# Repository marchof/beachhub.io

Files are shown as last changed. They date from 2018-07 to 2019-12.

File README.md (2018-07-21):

BeachHub.io
===========

Solar powered Git Repository and CI Server for beach usage built for the
[JCrete Unconference](http://www.jcrete.org).

* [Hardware](doc/hardware.md)
* [Energy Considerations](doc/energy.md)
* [Router Setup](doc/router.md)
* [System Setup](doc/setup.md)

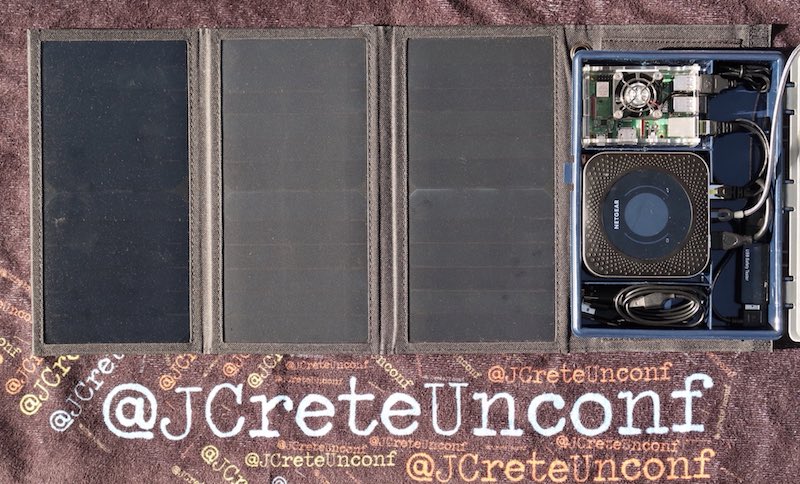
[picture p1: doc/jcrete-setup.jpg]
JCrete Setup


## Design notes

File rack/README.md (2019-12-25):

# 3D Models for Raspberry Pi Racks

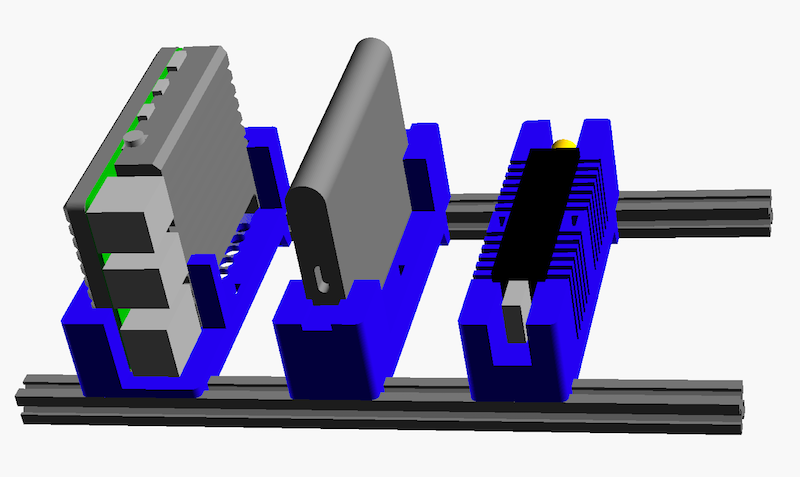
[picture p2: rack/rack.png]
Pi Rack


The rack is build from two supporting maker beams (10mm x 10mm).
There are holders for different modules I use for Raspberry Pi setups:

* Raspberry Pi with passive cooling Armor case
* External Samsung SSD
* Nooelec NESDR SMArt

These components are placed into the holders and fixed with a cable strap.

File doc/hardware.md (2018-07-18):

# Hardware

The following requirements were to consider when building the beachhub.io data center:

* **Power Supply:** The entire system should only be operated on solar power. Therefore total power consumption must be
  handled by a portable solar panel. To guarantee continuous operations a re-chargeable battery should buffer
  temporary drops in the solar power supply. For ease of integration I only considered distributing power with USB
  connections.
* **WiFi Access:** To make the hub accessible on the beach a WiFi network should be provided which lasts for at least a
  handful of devices.
* **Internet Connectivity:** The hub itself should have internet access and should also be accessible from the internet
  when active. Also it would be nice if the WiFi network could serve as a hotspot.

Considering these requirements I came up with the following setup:

## Solar Panels

I'm a big fan of Anker hardware for cables and power supplies. So my natural
choice was their *PowerPort Solar Charger 21W*. It has two USB ports with up to
2.4A each (but only 3A in total). You may easily figure out that this makes 15W
and not 21W as the name suggests -- but hey, this is how product marketing
works. Fortunately this is still enough for our setup. The panel is somehow
flexible and can be folded to a flat, portable package. The solar cells are
covered in a robust canvas which has four loops (each in every corner) so the
panel can be easily installed in different environments.

## Server

As a widely adopted low energy computing platform I picked a *Raspberry Pi 3 B+*
board. It has all the connectivity we need and is powerful enough to host Git
repos and maybe provide some simple means of continuous integration. I added
two persistent volumes to it:

1. A 32GB micro SD card for the operating system and all software
2. A small 64GB USB stick for all data (Git repos)

Separating the data from the system volumes allows me to update or re-stage the
system on the latter without worrying about the data.

To help with cooling under beach conditions I attached the heat sinks delivered
with the case and installed a small USB powered fan. It looks like the this
combination significantly reduces CPU temperature.

## 4G WIFI Router

While quite expensive though the best option currently on the market seems to be the Netgear Nighthawk M1. While it has
a quite compact form factor it encapsulates a gigabit 4G an WIFI router. A comparison with a stationary Huawai B593s-22
under identical, poor signal conditions showed that the signal received by the M1 is significant lower and so is the
bandwidth (Huawai 20 MBit/s down, 6 MBit/s up / Netgear 5 MBit/s down, 4MBit/s up). Maybe the signal strength can be
improved with external antennas. For this the M1 has two TS-9 connectors.

The router can be flexible configured and especially allows to map ports from the public IP to our Raspberry Pi for
access to BeachHub from the public internet (i.e. people not spending a nice day at the same beach). The WiFi provides a
2.4 GHz and a 5 GHz band and allows up to 20 concurrent user. Few even stationary routers come with such a feature set.

On top of this the hardware and its connectivity is ideal for our setup: There is one ethernet port which can be used for a
direct, reliable connection to the Raspberry Ri. It also comes with two different USB port: A USB-C port can be used for
charging from the solar panel. An additional USB 2.0 port provides power from its internal battery. We connect the raspberry
to this port for power supply. The nice side effect is that the internal router battery now serves as a kind of UPS for the
Raspberry Pi in case we have temporary drops in the solar power. What is also nice is that the power supply of the USB 2.0
port is switched with the router. So we can power up and down our whole data center with a single button.

## Mini USB Fan

As small small enough to directly fit in the Raspberry Pi case should help to
control the CPU temperature. It has an USB cable and its power consumption is
so small that it can be directly plugged in one of the Pi's USB ports.

## Wiring

For a minimal setup the wiring is quite simple:

- Long UBS 2.0/USB-C cable to connect the solar panel with the router (power supply)
- Short USB 2.0 cable to connect the router with the Raspberry Pi (power supply)
- The mini fan is plugged directly to a Raspberry Pi's USB port (power supply)
- Short ethernet cable to connect the router with the Raspberry Pi (network)

## Additional Hardware

- **Eithernet Hub** A small USB powered hub to connect additional devices if required.
- **Power Monitor** This small device can be plugged into a USB connection and shows voltage, current
  power and accumulated energy consumption. This device helped me to figure out what the solar panel
  actually can handle.

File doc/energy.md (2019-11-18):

# Power Management

With the USB tester plug I measured the following currents for the different BeachHub
devices. As all devices are powered with USB connectors the voltage is 5V in all cases.

Device                  | Min    | Max   
----------------------- | ------ | ------
Router (not charging)   | 0.25 A | 0.45 A     
Raspberry Pi 3 B+       | 0.38 A | 0.75 A
Mini Fan                | 0.12 A | 0.16 A

--> You can quantify power requirements of any specific device you have with lsusb -v and the MaxPower property.

## Bad Cables

It turned out that some of the USB cables I tested cause such a significant voltage
drop that the Raspberry Pi goes off. To avoid such surprises I checked all cables
used in BeachHub with the USB tester:

1. Find a constant and strong power source (charger or large power bank)
2. Connect a heavy load (empty smart phone oder battery back) with a the USB tester
   to the power source. Write down the voltage shown by the tester.
3. Now insert the cable in question between the power source and the USB tester.
   Note the voltage shown now.
 
If the voltage is decreased by more that 0.2V or the voltage measured in step 3
is less than 4.8V you can't run a Raspberry Pi reliable on this cable.

## Under Voltage

If the supplied voltage is too low the CPU gets throttled. With the following command you can check whether this or was the case:

    vcgencmd get_throttled
    
The bits in the returned integer have the following meanings:

| Bit | Meaning |
|:---:|---|
| 0 | Under-voltage detected |
| 1 | Arm frequency capped |
| 2 | Currently throttled |
| 3 | Soft temperature limit active |
| 16  | Under-voltage has occurred |
| 17  | Arm frequency capped has occurred |
| 18  | Throttling has occurred |
| 19  | Soft temperature limit has occurred |

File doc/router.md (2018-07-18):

# Router Setup

I performed the following steps with the Netgear Nighthawk M1 router using its web
interface on `http://192.168.1.1`.

1. **Router Password**
   On first login the router password must be set
2. **Mobile Internet**
   For most mobile operators the SIM card should be detected without further APN
   configuration. Make sure the SIM security is deactivated or you need to enter
   PIN on every startup. You may also enable the roaming option if you want to
   run the device on foreign beaches. In this case the SIM should have an
   international data plan of course.
3. **Firmware Update**
   For the latest bug fixes perform an update under *Administration / Firmware Update*.
4. **WiFi**
   Under *Setup / Wifi Profiles* select *2.5 GHz Only* to save energy.
   Under *Setup / Wireless* set a SSID and password for the 2.4 GHz network.
   For best wireless experience set the WiFi standby to *60 Minutes* and the
   range to *Long*.
5. **USB Port**
   As we use the USB port for charging only under *Setup / Mobile Router Setup*
   set *Tethering* to *Charge only*.
6. **Ethernet**
   To avoid disconnecting the Raspberry Pi from under *Setup / Mobile Router Setup*
   select *Disabled* for *Ethernet Standby*.

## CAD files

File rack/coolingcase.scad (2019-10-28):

// Beachhub Pi Rack Geometries

// Global resolution
$fs = 0.1;  // Don't generate smaller facets than 0.1 mm
$fa = 5;    // Don't generate larger angles than 5 degrees

use <raspberrypi.scad>;

module _cone() {
  translate([0.0, 0.0, -5.0]) cylinder(h=18.0, r=2.0);
  translate([0.0, 0.0, 13.0]) cylinder(h=2.0, r1=2.0, r2=0.0);
  translate([0.0, 0.0, -7.0]) cylinder(h=2.0, r1=0.0, r2=2.0);
}

module _block() {
  hull() {
    translate([40.5, 26.0, 0.0]) _cone();
    translate([40.5, -26.0, 0.0]) _cone();
    translate([-40.5, 26.0, 0.0]) _cone();
    translate([-40.5, -26.0, 0.0]) _cone();
  }
}

module coolingcase() {
  color("gray")
  difference() {
    _block();
    // cooling top
    for (y = [-22.0 : 4.7 : 17.0])
      translate([-45.0, y, 13.0]) cube([90.0, 2.3, 4.0]);
    // cooling bottom
    for (y = [-22.0 : 4.2 : 22.0])
      translate([-45.0, y, -9.0]) cube([90.0, 2.0, 4.0]);
    // board
    translate([-45.0, -30.0, 0.0]) cube([90.0, 60.0, 2.0]);
    // USB/network ports
    translate([23.0, -30.0, 0.0]) cube([23.0, 60.0, 20.0]);
    // GPIO pins
    hull() {
      translate([14.5, 22.0, 0.0]) cylinder(h=18.0, r=2.0);
      translate([-35.5, 22.0, 0.0]) cylinder(h=18.0, r=2.0);
      translate([14.5, 30.0, 0.0]) cylinder(h=18.0, r=2.0);
      translate([-35.5, 30.0, 0.0]) cylinder(h=18.0, r=2.0);
    }
  }
}



//pi4();
coolingcase();

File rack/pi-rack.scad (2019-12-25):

// Beachhub Pi Rack Geometries

// Global resolution
$fs = 0.1;  // Don't generate smaller facets than 0.1 mm
$fa = 5;    // Don't generate larger angles than 5 degrees

use <raspberrypi.scad>;
use <coolingcase.scad>;
use <ssd.scad>;
use <sdr.scad>;

module beam(length) {
    color("Gray")
    linear_extrude(height=length)
    polygon([[0.0,0.0], [3.5,0.0], [3.5,1.0], [2.0,1.0], [4.0,3.0], [6.0,3.0], [8.0,1.0], [6.5,1.0], [6.5,0.0],
      [10.0,0.0], [10.0,3.5], [9.0,3.5], [9.0,2.0], [7.0,4.0], [7.0,6.0], [9.0,8.0], [9.0,6.5], [10.0,6.5], 
      [10.0,10.0], [6.5,10.0], [6.5,9.0], [8.0,9.0], [6.0,7.0], [4.0,7.0], [2.0,9.0], [3.5,9.0], [3.5,10.0],
      [0.0,10.0], [0.0,6.5], [1.0,6.5], [1.0,8.0], [3.0,6.0], [3.0,4.0], [1.0,2.0], [1.0,3.5], [0.0,3.5]]);
}


module flap(width) {
    difference() {
      linear_extrude(height=width) polygon([[0.0,0.0], [6.0,0.0], [6.0,2.0], [3.0,10.0], [0.0,10.0]]);
      translate([2.0, 0.0, 2.0]) cube([10.0, 10.0, width - 4.0]);
      translate([-2.0, 5.0, width / 2]) rotate([0, 90, 0]) cylinder(h=10.0, r=1.5);
    }
}

module base(width, length, height) {
  flap(width);
  translate([length - 20 , 0, 0]) mirror([1,0,0]) flap(width);
  hull() {
    translate([length - 12.0, 0.0, 2.0]) rotate([90, 0, 0]) cylinder(h=height, r=2.0);
    translate([-8.0, 0.0, 2.0]) rotate([90, 0, 0]) cylinder(h=height, r=2.0);
    translate([-8.0, 0.0, width - 2.0]) rotate([90, 0, 0]) cylinder(h=height, r=2.0);
    translate([length - 12.0, 0.0, width - 2.0]) rotate([90, 0, 0]) cylinder(h=height, r=2.0);
  }
  translate([0.0, 0.0, 0.0]) cube([length - 20.0, 4.0, 2.0]);
  translate([0.0, 0.0, width - 2.0]) cube([length - 20.0, 4.0, 2.0]);
  translate([-6.4, 0.0, 1.0]) cube([2.8, 2.0, width - 2.0]);
  translate([length - 16.6, 0.0, 0.0]) cube([2.8, 2.0, width]);
}

module piholder() {
  color("Blue") {
    difference() {
      base(35, 100, 25);
      group() {
        translate([ -2.5, -27.0,  6.0]) cube([85.5, 25.0, 22.0]);
        translate([1.5, -28.0, -2.0]) cube([56.0, 25.0, 40.0]);
        translate([62.5, -28.0, 13.0]) cube([56.0, 25.0, 30.0]);
        // fixation
        translate([40.5, -4.0, 2.0]) cube([5.0, 6.0, 2.0]);
        translate([40.5, -4.0, 31.0]) cube([5.0, 6.0, 2.0]);
        // SD card
        translate([-12.0, -27.0, 10.0]) cube([10.0, 6.0, 6.0]);
        for (x = [7.0 : 6.0 : 75.0]) {
          translate([x, 1.0,  9.5]) rotate([90, 0, 0]) cylinder(h=5.0, r=2.5);
          translate([x, 1.0, 19.5]) rotate([90, 0, 0]) cylinder(h=5.0, r=2.5);
        }
        for (x = [10.0 : 6.0 : 75.0]) {
          translate([x, 1.0, 14.5]) rotate([90, 0, 0]) cylinder(h=5.0, r=2.5);
          translate([x, 1.0, 24.5]) rotate([90, 0, 0]) cylinder(h=5.0, r=2.5);
        }
      }
    }
  }
}

module ssdholder() {
  color("Blue") {
    difference() {
      base(25, 100, 25);
      group() {
        translate([2.0, -8.0, 12.5]) ssd();
        translate([10.0, -37.0, -2.5]) cube([60.0, 30.0, 30.0]);
        // USB connector
        translate([-15.0, -33.0, 8.5]) cube([110.0, 10.0, 8.0]);
        // fixation
        translate([37.5, -8.0, 3.0]) cube([5.0, 10.0, 2.0]);
        translate([37.5, -8.0, 20.0]) cube([5.0, 10.0, 2.0]);
        for (x = [7.0 : 6.0 : 75.0]) {
          translate([x, 1.0, 12.5]) rotate([90, 0, 0]) cylinder(h=5.0, r=2.5);
        }
      }
    }
  }
}

module sdrholder() {
  color("Blue") {
    difference() {
      base(26, 100, 25);
      group() {
        translate([10.5, -28.0,  6.0]) cube([61.0, 17.0, 14.0]);
        // fixation
        translate([40.5, -28.0, 2.0]) cube([5.0, 30.0, 2.0]);
        translate([40.5, -28.0, 22.0]) cube([5.0, 30.0, 2.0]);
        // connectors
        translate([-15.0, -29.0, 8.0]) cube([110.0, 17.0, 10.0]);
        // cooling
        translate([12.0, -34.0, -2.0]) cube([2.0, 30.0, 30.0]);
        translate([12.0, -8.0,   9.0]) cube([2.0, 10.0, 8.0]);      
        translate([16.0, -34.0, -2.0]) cube([2.0, 30.0, 30.0]);        
        translate([16.0, -8.0,   9.0]) cube([2.0, 10.0, 8.0]);      
        translate([20.0, -34.0, -2.0]) cube([2.0, 30.0, 30.0]);        
        translate([20.0, -8.0,   9.0]) cube([2.0, 10.0, 8.0]);      
        translate([24.0, -34.0, -2.0]) cube([2.0, 30.0, 30.0]);        
        translate([24.0, -8.0,   9.0]) cube([2.0, 10.0, 8.0]);      
        translate([28.0, -34.0, -2.0]) cube([2.0, 30.0, 30.0]);        
        translate([28.0, -8.0,   9.0]) cube([2.0, 10.0, 8.0]);      
        translate([32.0, -34.0, -2.0]) cube([2.0, 30.0, 30.0]);        
        translate([32.0, -8.0,   9.0]) cube([2.0, 10.0, 8.0]);      
        translate([36.0, -34.0, -2.0]) cube([2.0, 30.0, 30.0]);        
        translate([36.0, -8.0,   9.0]) cube([2.0, 10.0, 8.0]);
   
        translate([40.0, -8.0,   9.0]) cube([2.0, 10.0, 8.0]);
        translate([44.0, -8.0,   9.0]) cube([2.0, 10.0, 8.0]);
   
        translate([48.0, -34.0, -2.0]) cube([2.0, 30.0, 30.0]);        
        translate([48.0, -8.0,   9.0]) cube([2.0, 10.0, 8.0]);      
        translate([52.0, -34.0, -2.0]) cube([2.0, 30.0, 30.0]);        
        translate([52.0, -8.0,   9.0]) cube([2.0, 10.0, 8.0]);      
        translate([56.0, -34.0, -2.0]) cube([2.0, 30.0, 30.0]);        
        translate([56.0, -8.0,   9.0]) cube([2.0, 10.0, 8.0]);      
        translate([60.0, -34.0, -2.0]) cube([2.0, 30.0, 30.0]);        
        translate([60.0, -8.0,   9.0]) cube([2.0, 10.0, 8.0]);      
        translate([64.0, -34.0, -2.0]) cube([2.0, 30.0, 30.0]);        
        translate([64.0, -8.0,   9.0]) cube([2.0, 10.0, 8.0]);      
        translate([68.0, -34.0, -2.0]) cube([2.0, 30.0, 30.0]);        
        translate([68.0, -8.0,   9.0]) cube([2.0, 10.0, 8.0]);      

        translate([12.0, -12.0, 13.0]) rotate([0, 90, 0]) cylinder(h=58.0, r=5);
      }
    }
  }
}


translate([-10, 0, 0]) beam(200);
translate([80, 0, 0]) beam(200);


translate([0, 0, 20]) piholder();
translate([40.0, -30.0, 33.0]) {
    coolingcase();
    pi4();
}

translate([0, 0, 80]) {
    ssdholder();
    translate([2.0, -8.0, 12.5]) ssd();
}

translate([0, 0, 130]) {
    sdrholder();
    sdr();
}

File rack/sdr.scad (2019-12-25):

// SDR Stick

// Global resolution
$fs = 0.1;  // Don't generate smaller facets than 0.1 mm
$fa = 5;    // Don't generate larger angles than 5 degrees

module sdr() {
  color("Black") {
    translate([10.5, -28.0,  6.0]) cube([61.0, 17.0, 14.0]);
  }
  color("Silver") {
    translate([71.5, -25.5,  10.5]) cube([11.0, 12.0, 5.0]);
  }
  color("Gold") {
    translate([-1.5, -19.5,  13.0]) rotate([0, 90, 0]) cylinder(h=12.0, r=4.0);
  }
}

sdr();

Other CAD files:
rack/ssd.scad
rack/raspberrypi.scad

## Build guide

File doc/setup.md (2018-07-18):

# System Setup

## System SD Card

The raspberry pi boots from a Mini SD card. I use this card exclusively for the system setup. All persistent
data is kept on an extra USB memory stick. This allows me to re-stage the system whenever I want to change
its configuration.

Prepare SD card with latest Raspbian light image (`yyyy-mm-dd-raspbian-stretch-lite.zip`) e.g. using e.g. Etcher on OSX.

Create empty file named `ssh` in root folder of the `boot` partition if the SD card to enable ssh login:

    $ touch /Volumes/boot/ssh

Insert the SD card into the raspberry pi.

## Raspberry Pi Setup With Ansible

Do initial setup for device name and user password (default password for fresh raspbian images is `raspberry`):

    $ ansible-playbook -i hosts -k init.yml
    
Reboot the raspberry pi and add a USB storage for Git repositories with label `DATA`.

Install beachhub software and configurations:
    
    $ ansible-playbook -i hosts install.yml

Add public key of user `tunnel` to web proxy host.

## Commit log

2018-07-03 Mount memory stick
2018-07-03 Fix mount permissions, install git.
2019-10-28 3D model for raspberry pi rack
    [coolingcase.scad, pi-rack.scad, raspberrypi.scad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]
2019-10-28 Reduce length to 100mm
    [pi-rack.scad]
2019-10-28 Base with round corners
    [pi-rack.scad]
2019-12-25 Add SDR Holder
    [pi-rack.scad, sdr.scad]
